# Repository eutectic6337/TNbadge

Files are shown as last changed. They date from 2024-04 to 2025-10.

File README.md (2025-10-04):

# TNbadge

A blinky-light badge in the approximate shape of Tennessee

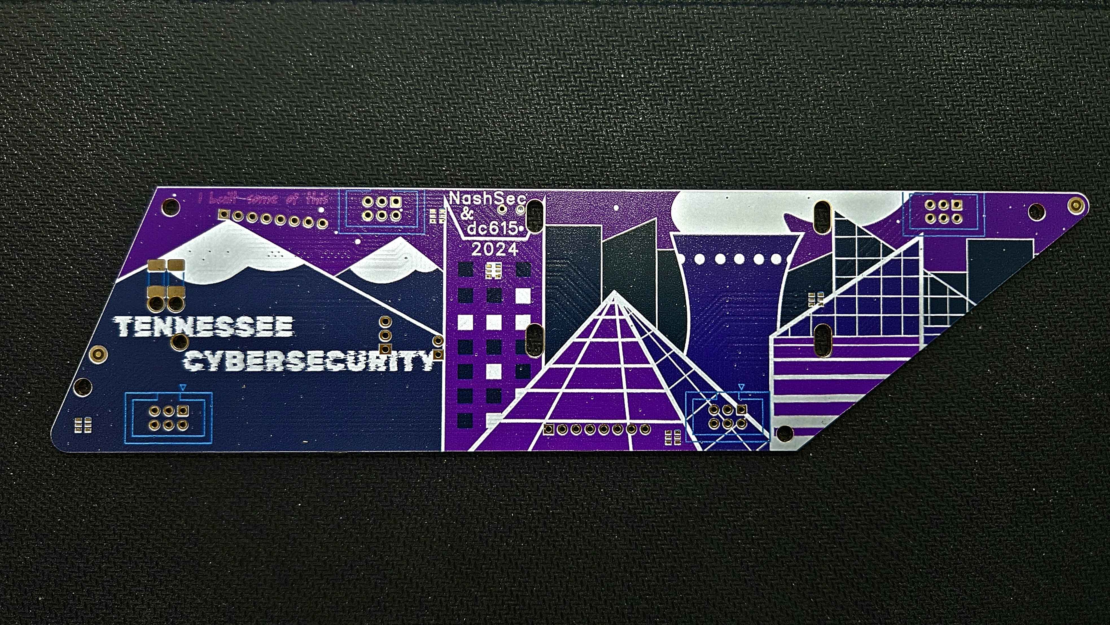
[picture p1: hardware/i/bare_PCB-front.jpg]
PCB front


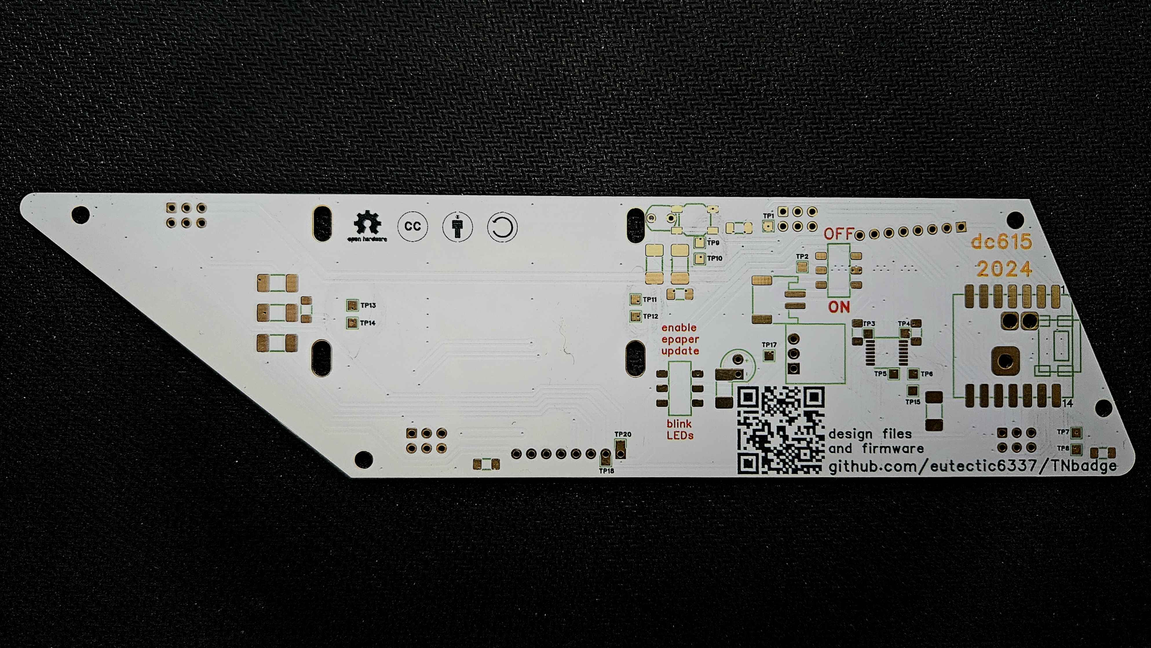
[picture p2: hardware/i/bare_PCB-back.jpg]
PCB back


[Join the Tennessee Cybersecurity Discord](https://discord.gg/tninfosec) and
[participate in discussion about this badge](https://discord.com/channels/781280955667185686/1010244036612862144).

[User's Guide](users-guide.md)

## Features

### human-accessible output
- 5 of [2.0mm square addressable RGB LED (APA102)](https://www.aliexpress.us/item/2251832665711027.html)
at the approximate locations of the top 5 population centres
(west to east: Memphis, Clarksville, Nashville, Chattanooga, Knoxville)  
on-chip SPI (SCLK from pin 9 (D8/GPIO8), MOSI from pin 11 (D10/GPIO10))

- 1 of user-populated [LED](https://www.aliexpress.us/item/3256802159185271.html)-footprint,
[switched](https://www.aliexpress.us/item/2251832541429715.html)
[5V supply](https://www.aliexpress.us/item/3256801453688823.html)
with current-limiting resistor  
from pin 7 (D6/GPIO21)

- 1 of [212x104 pixel 2.13 inch epaper display (grey/black/red)](https://www.aliexpress.us/item/3256806569318405.html)
populated at either of 2 locations
(one almost entirely on-board; one almost entirely off-board and mounted from behind to not obscure Chattanooga's LED)  
on-chip SPI, /CS from pin 4 (D3/GPIO5), DATA/CMD from pin 2 (D1/GPIO3), /RESET from pin 7 (D6/GPIO21), BUSY to pin 1 (D0/GPIO2)

### human-accessible input
- 1 of LDR, darkness-proportional voltage at ADC  
to pin 3 (A3/D3/GPIO5)  
*unfortunately, the chip configuration in Espressif's Arduino chip-support package connects a non-functional ADC to this pin, so this can't work without a deeper dive* :(

- 1 of [pushbutton](https://www.aliexpress.us/item/2251832616067755.html)
digital input to pin 10 (D9/GPIO9)

### electronic
- 1 .. 3 of [SAO V.1.69bis master connector](https://www.aliexpress.us/item/2251832874579437.html)
populated at any of 4 locations not obstructed by epaper  
on-chip I2C (SCL on pin 6 (D5/GPIO7), SDA on pin 5 (D4/GPIO6)), GPIO1 on pin 2 (D1/GPIO3), GPIO2 on pin 1 (D0/GPIO2)

- [USB-C](https://www.aliexpress.us/item/2251832621183502.html)
for power and programming

- [1000mAh LiPo battery](https://www.aliexpress.us/item/3256803012248557.html)

- battery voltage /2 at ADC  
to pin 3 (A2/D2/GPIO4)

- on-chip Bluetooth Low Energy / WiFi

- [power ON/OFF switch](https://www.aliexpress.us/item/2255799844067525.html)

- [epaper display / LED enable switch](https://www.aliexpress.us/item/2255799844067525.html)
(to maximize epaper lifetime by disconnecting power other than when required for update,
and encourage this by having LED power mutually exclusive with epaper power)

## design considerations
- minimal components on front allowing maximum space for silkscreen art

- maximal GND-connected fill on both top and bottom for even background under soldermask (and to reduce electrical noise)

- flat empty space on back for LiPo battery to rest snug against PCB

- maximum flexibility for user customization, both physical and logical

- components chosen (and footprints customized) for hand-solderability where possible

## software
[prototype implementation](https://github.com/eutectic6337/TNbadge/tree/main/software/prototype-1)

ideally, watches for pushbutton held down at boot to signal display update requested;
after display is updated, user flips epaper/LED switch for blinky goodness

possible behaviour-change triggers:
- ambient light level

- dropping battery voltage

- proximity of other badges, which specific badges they are, and *their* interaction history

- external access over BLE/WiFi by not-a-badge

# production timeline
Board design is now locked down.

- First batch of badge kits
(SMD components soldered onto PCB, through-hole assembly to be completed by user)
distributed in April 2024 to software development volunteers

- Artwork has been added to board silkscreen

- epaper displays are now in hand

- remaining PCBs to be delivered mid June

- remaining CPU modules to be ordered mid June

- SMD assembly to start when PCBs arrive

- bagged kits distributed as soon as possible, but no later than
[DEF CON 32](https://defcon.org) in Las Vegas

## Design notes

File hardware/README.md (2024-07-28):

# TNbadge hardware

## Kit

[assembly guide](Kit-assembly.md)

## Printed Circuit Board

- designed in Kicad

- imported into [EasyEDA Pro](https://pro.easyeda.com)

   - manually reattached lanyard/stencil-alignment holes, battery box slots, an zero-size holes to net GND
 with direct connect (i.e. no thermal relief)

   - manually reattached quarter-circle track around pin 2 of epaper display connector, top left,
to net /GPIO1{SLASH}DC

   - manually re-edited APA102 footprint to remove solder mask/stencil openings over (center) duplicate GND/5V pads

   - manually edited all testpoints to show correct designator, on back silkscreen layer

   - manually imported QR code PNG (M1) onto back silkscreen layer (Kicad plays poorly)

   - manually adjusted color of silkscreen artifacts

- multicolour PNG artwork imported to front silkscreen layer

- ordered from [JLC PCB](https://jlcpcb.com)

## component sources

- already in hand (through-hole LDRs)

- [LCSC](https://lcsc.com) (SMD resistors & capacitors)

- [Seeed Studio](https://seeedstudio.com) (CPU module)

- [AliExpress](https://aliexpress.com) (everything else)

# assembly and test

## front surface mount

### assemble

- position PCB back-down on stable heat-resistant surface

- stencil solder paste on front

- [place](i/00-100k-b.jpg) [2x 100k resistor](i/00-100k-a.jpg) (2010)  
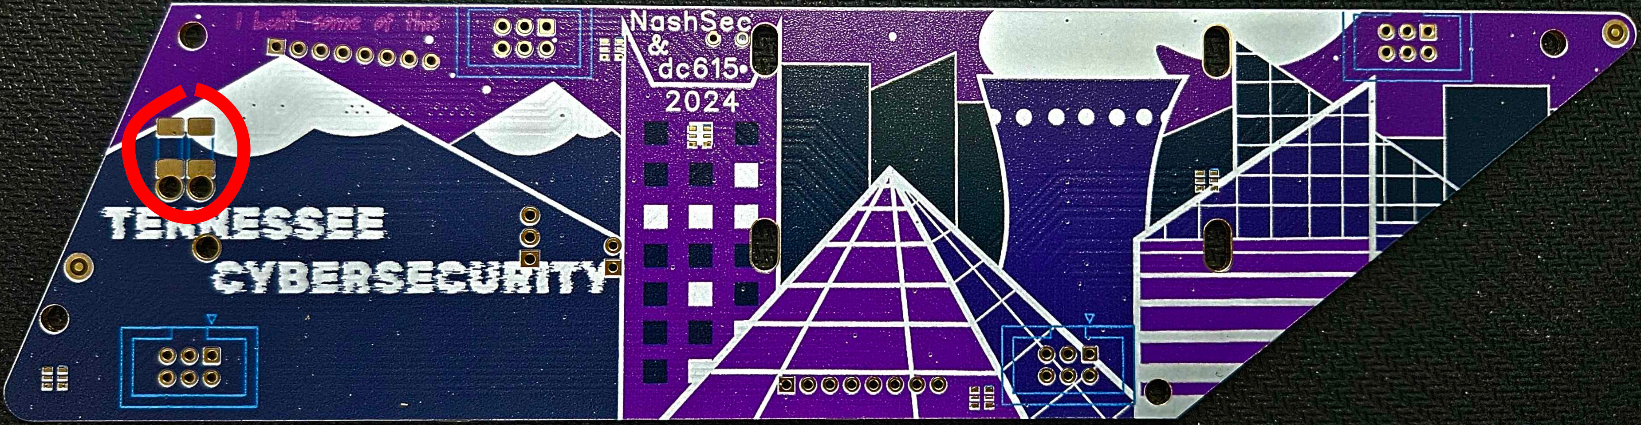
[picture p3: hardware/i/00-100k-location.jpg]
100k location


- [place](i/03-APA102-b.jpg) 5x [APA102 addressable RGB LED](i/03-APA102-a.jpg) (2020)  
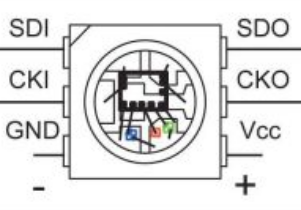
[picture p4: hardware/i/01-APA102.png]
APA102 datasheet

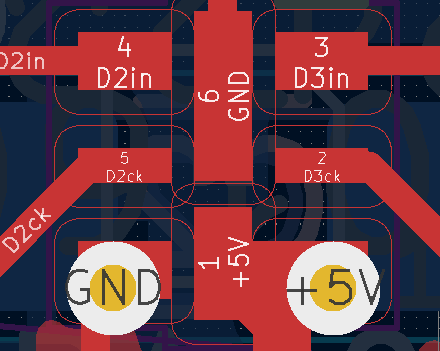
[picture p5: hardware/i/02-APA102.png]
APA102 footprint

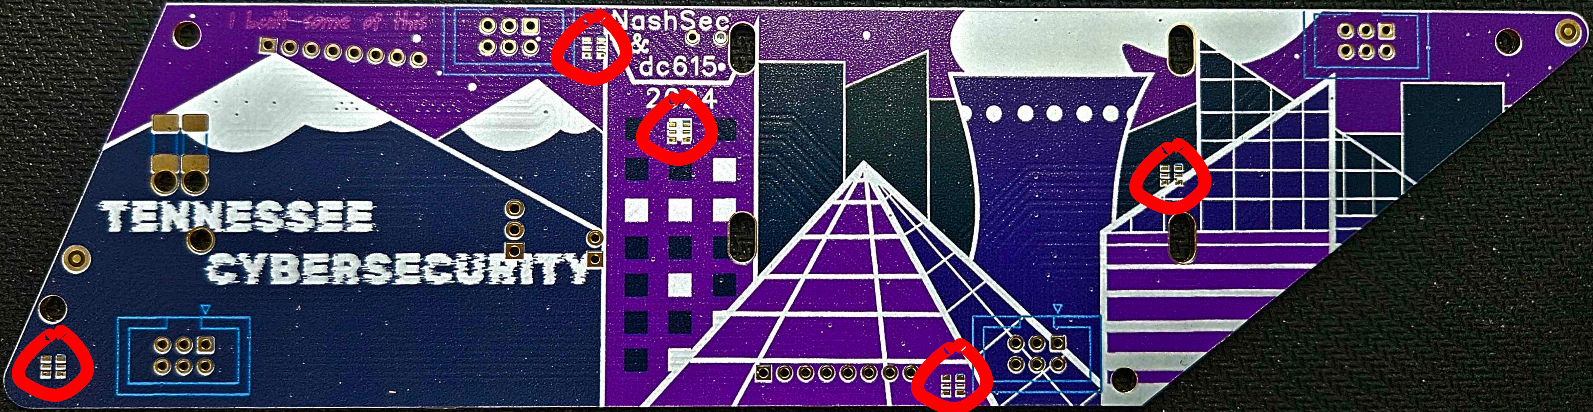
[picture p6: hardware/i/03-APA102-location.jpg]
APA102 location


- (optional) preheat to 100 degC

- apply hot air at 200+ degC to each component until solder flows to create concave surface

### test

- position board front-down on stable non-conductive surface

- starting at lower right corner, test continuity between each pair of pads from the set
{test points, CPU pads}

- continuity is expected between

   - TP1 CPU13 CPU\_GND CPU\_BAT-

   - TP2 CPU\_BAT+

   - TP3 CPU12

   - TP15 CPU8

   - TP18 CPU7

   - TP20 CPU1

- continuity between any pair of test points,
or between any pair of CPU pads,
or between any other test points and CPU pads
indicates a likely solder bridge

- continuity between any of TP5 through TP14 and TP4 or TP1
indicates a bridge between pads of one of the smart LEDs either side of the
involved TP5...TP14

Data point: after soldering only the front components (5x smart LED, 2x resistor) on 5 boards,
I had *1* board with no erroneous beeps in the continuity test.

### rectify

For each identified fault

- desolder identified likely culprit components

- flux and wick up solder from PCB

- re-test to verify fault is gone; if fault remains, dig deeper

- flux pads and reposition component

- reflow remaining solder

- add minimal solder if needed

- re-test to verify fault is gone

Mr Clumsyhands has found a trap for young players:
once you've played some hot air over a SMD LED,
its little transparent top becomes soft enough for your tweezers to wipe it off,
along with the actual silicon bits underneath, if you twitch while applying pressure to the side of the package.

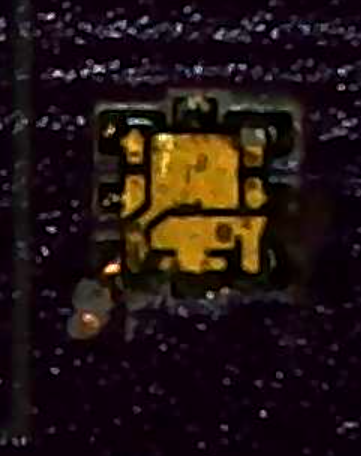
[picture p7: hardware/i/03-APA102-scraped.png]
APA102 scraped


So, don't do that.

## back surface mount

### assembly

- position PCB front-down on stable heat-resistant surface

- stencil solder paste on back

- [place](i/04-TXS0104-b.jpg) [1x level shifter chip](i/04-TXS0104-a.jpg) (TSSOP)
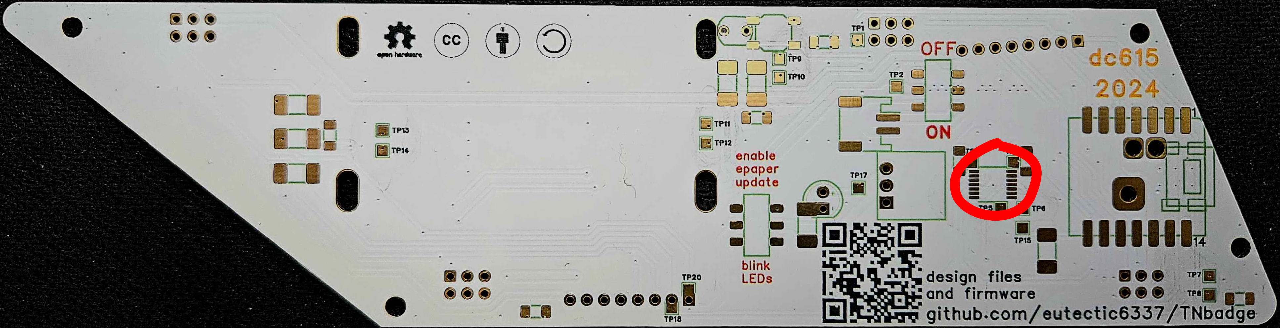
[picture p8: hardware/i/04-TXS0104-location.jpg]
level shifter location


- [place](i/05-pbsw-b.jpg) [1x pushbutton switch](i/05-pbsw-a.jpg)
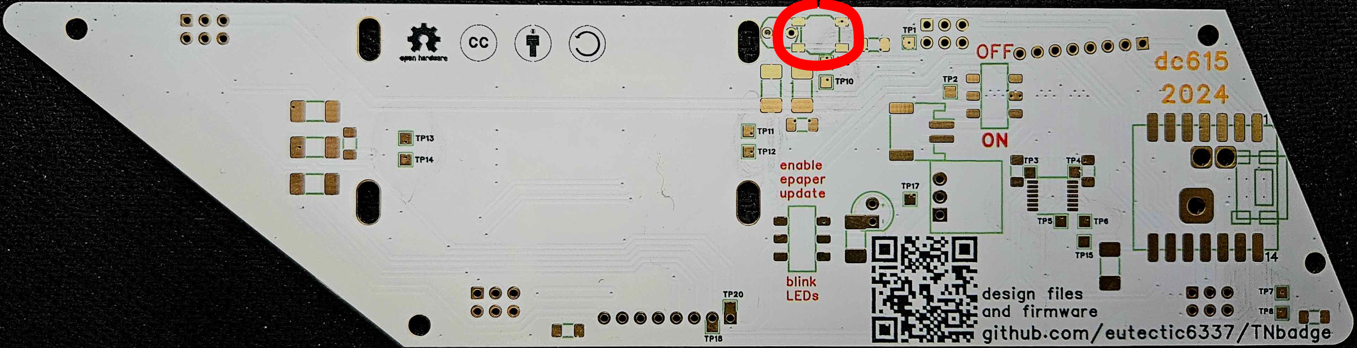
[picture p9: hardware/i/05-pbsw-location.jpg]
pushbutton location


- place 1x 100 ohm resistor (2010)
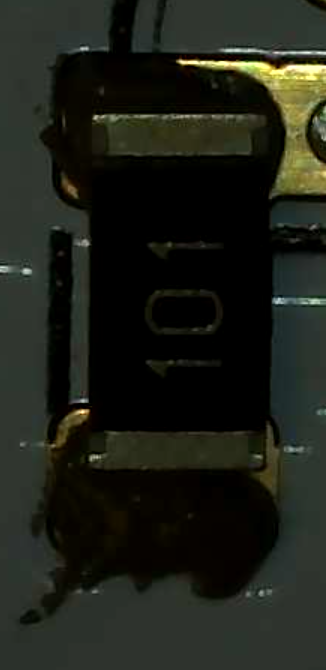
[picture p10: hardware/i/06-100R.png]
100 ohm surface mount resistor


- [place](i/07-10k-b.jpg) 6x [10k resistor](i/07-10k-a.jpg) (2010)
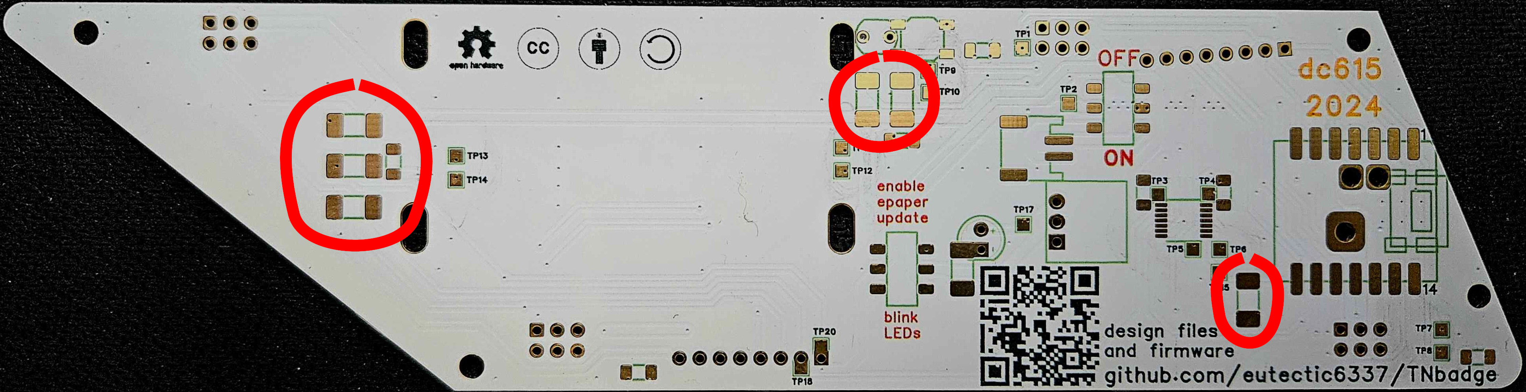
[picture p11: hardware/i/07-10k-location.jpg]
10k location


- [place](i/08-1uF-b.jpg) 7x [1uF capacitor](i/08-1uF-a.jpg) (1206)
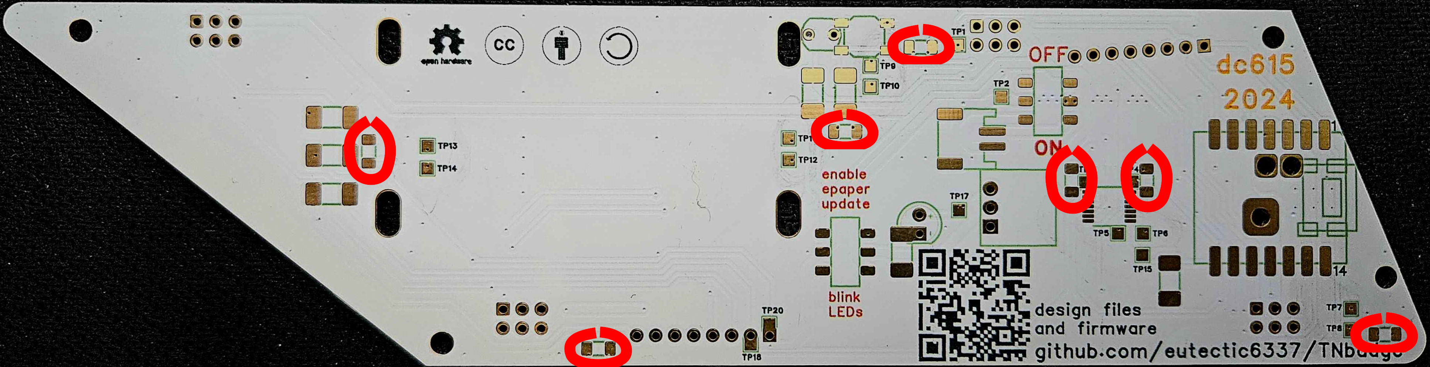
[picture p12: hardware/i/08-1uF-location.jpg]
1uF location


- [place](i/09-pow_sw-b.jpg) 2x [slide switch](i/09-pow_sw-a.jpg)
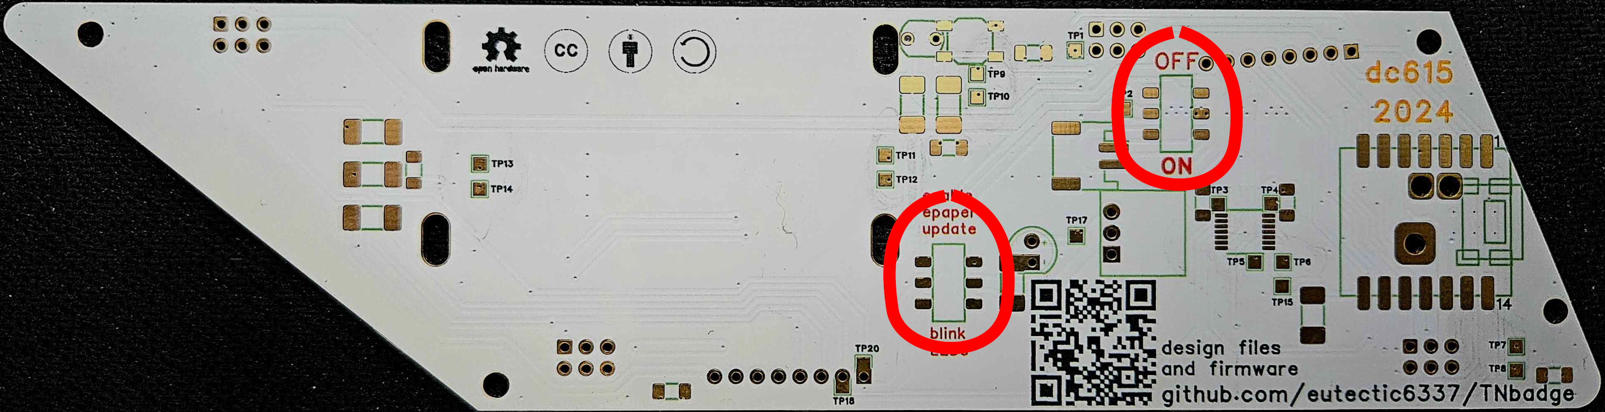
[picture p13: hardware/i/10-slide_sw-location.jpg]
slide switch location


- [place](i/11-batcon-a.jpg) [1x battery connector](i/11-batcon-a.jpg)
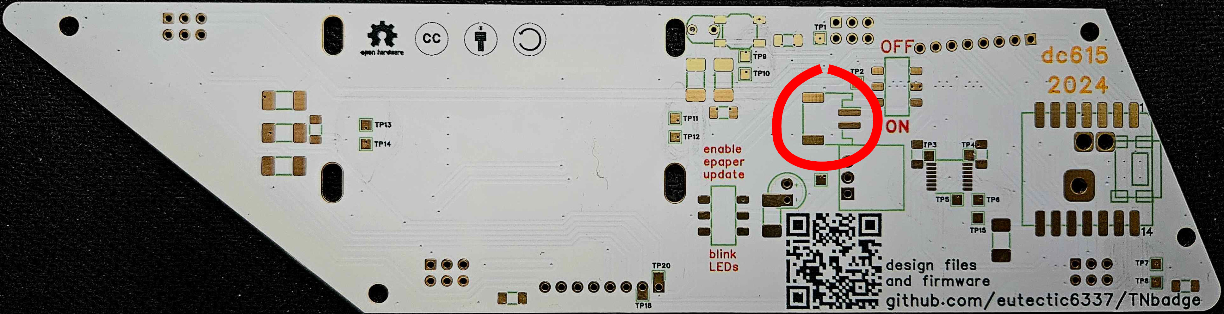
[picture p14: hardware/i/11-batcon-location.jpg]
battery connector location


- (optional) preheat to 100 degC

- apply hot air at 200+ degC to each component until solder flows to create concave surface

### test

- position board front-down on stable non-conductive surface

- starting at lower right corner, test continuity between each pair of pads from the set
{test points, CPU pads}

- continuity is expected between

   - TP1 CPU13 CPU\_GND CPU\_BAT-

   - TP2 CPU\_BAT+

   - TP3 CPU12

   - TP15 CPU8

   - TP18 CPU7

   - TP20 CPU1

- continuity between any pair of test points,
or between any pair of CPU pads,
or between any other test points and CPU pads
indicates a likely solder bridge

### rectify

most likely location for bridge is TSSOP level shifter chip

- flux and wick up excess solder from pins on one side

- drag-solder with small wedge/chisel tip iron to reflow remaining solder

- re-test to verify fault is gone; if fault remains, dig deeper

For each other identified fault

- desolder identified likely culprit components

- flux and wick up solder from PCB

- re-test to verify fault is gone; if fault remains, dig deeper

- flux pads and reposition component

- reflow remaining solder

- add minimal solder if needed

- re-test to verify fault is gone

## CPU module

### assembly

- position PCB front-down on stable heat-resistant surface

- apply small dot of solder paste on each of 14 main CPU pads on PCB

- place ESP32C3 CPU module
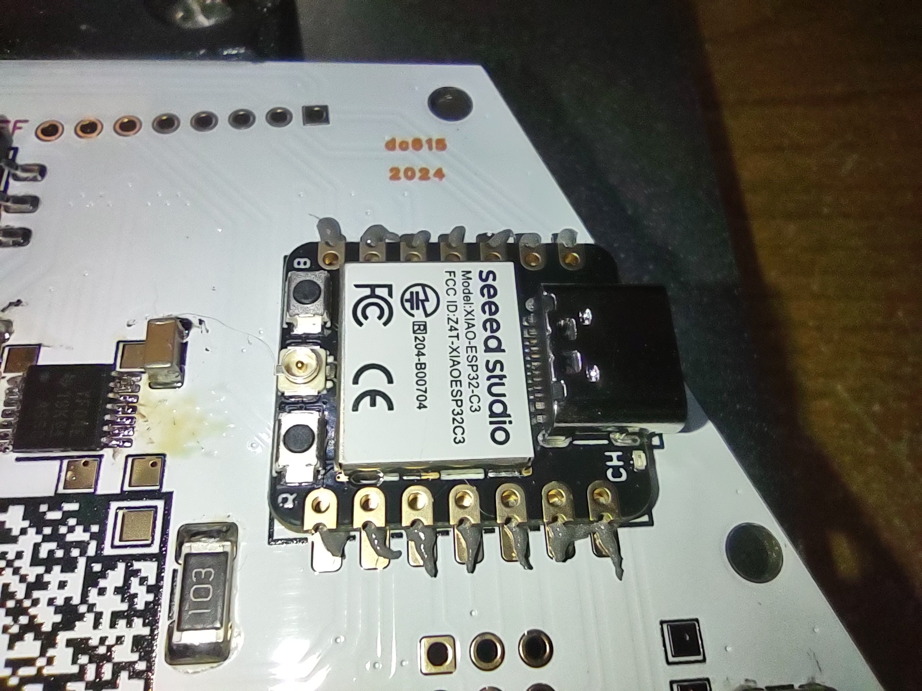
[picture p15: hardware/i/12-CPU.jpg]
CPU module


- apply hot air at 200+ degC to each long edge of CPU carrier board
until solder flows to create concave surface
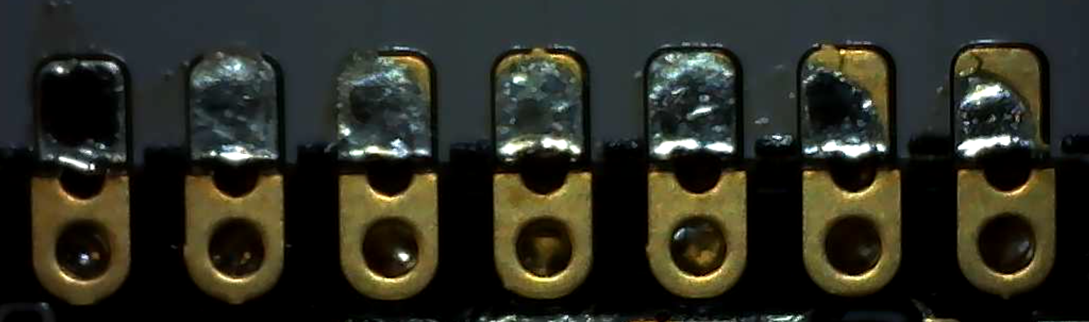
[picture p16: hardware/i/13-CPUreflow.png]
CPU pads after reflow

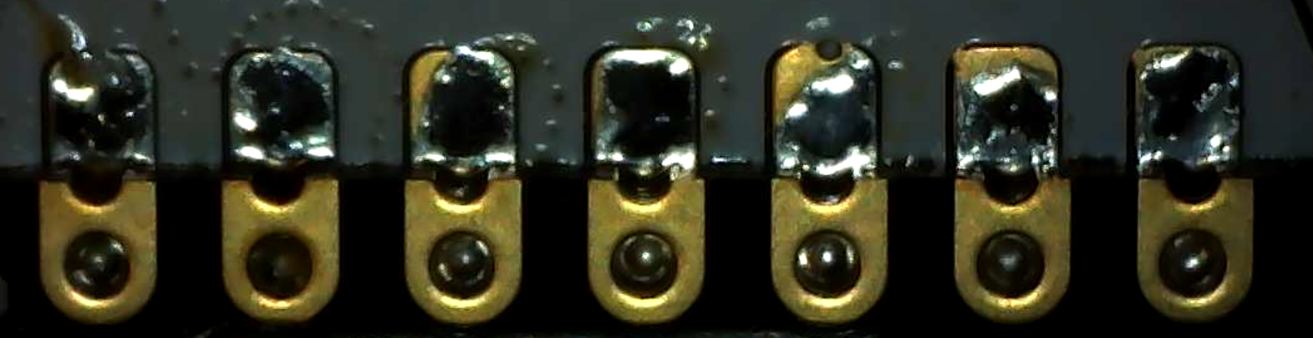
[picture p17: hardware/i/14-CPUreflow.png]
CPU pads after reflow


- position PCB back-down on stable heat-resistant surface

- apply small dot of solder paste in each of 3 through-holes under CPU module
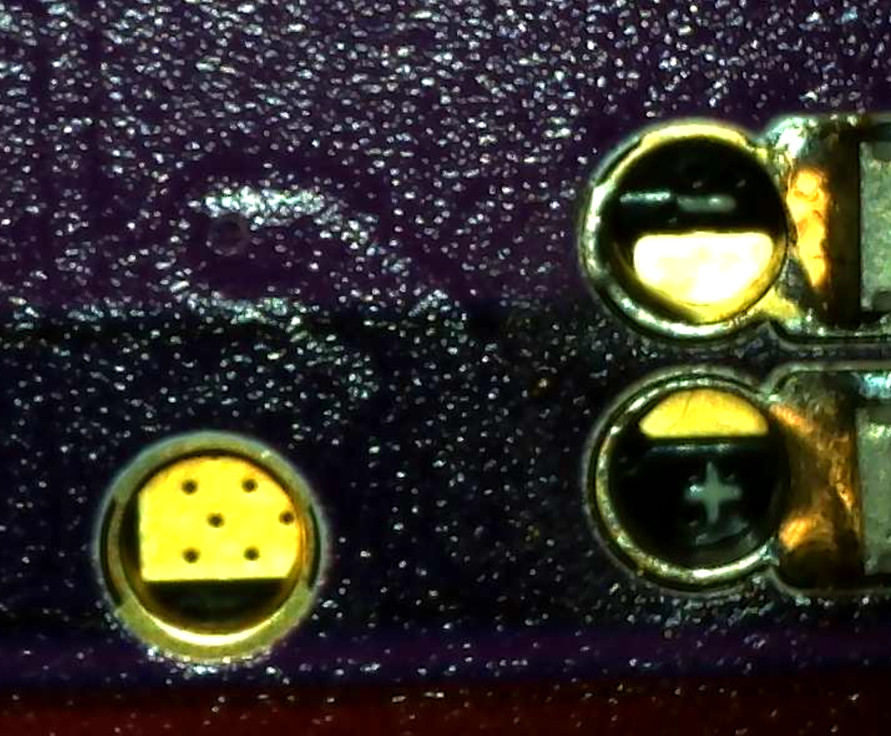
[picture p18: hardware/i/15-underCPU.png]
view through holes to CPU module

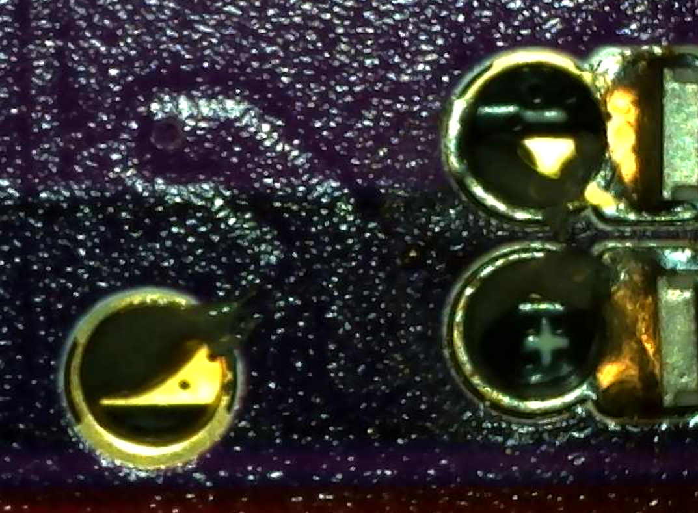
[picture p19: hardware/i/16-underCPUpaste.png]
solder paste in holes


- apply hot air at 200+ degC to holes under CPU carrier board
until solder flows to create concave surface
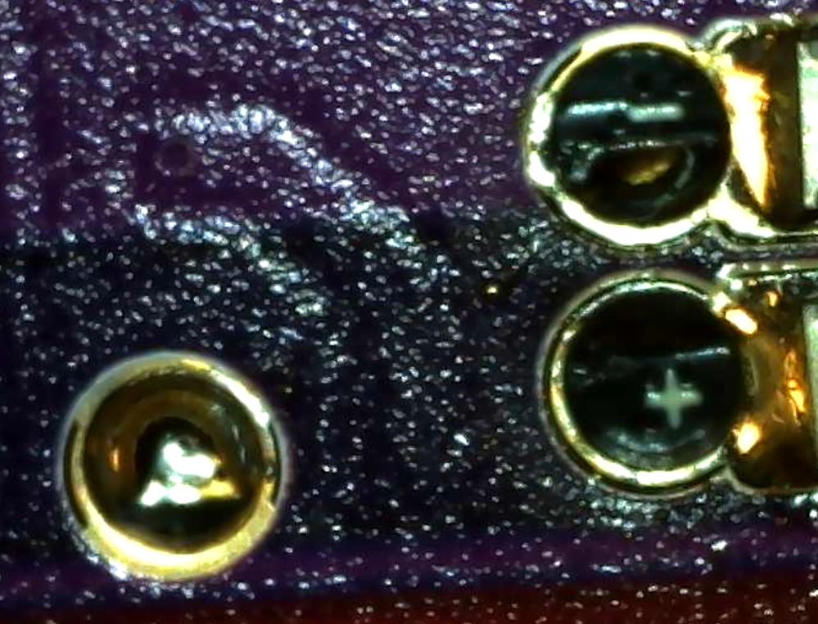
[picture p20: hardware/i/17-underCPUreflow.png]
reflowed solder in holes


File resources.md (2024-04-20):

[public repo](https://github.com/eutectic6337/TNbadge)

# Xiao ESP32C3

[order MCU module](https://www.seeedstudio.com/Seeed-XIAO-ESP32C3-p-5431.html)

[MCU docs](https://wiki.seeedstudio.com/XIAO_ESP32C3_Getting_Started/)

[Arduino support pack](https://raw.githubusercontent.com/espressif/arduino-esp32/gh-pages/package_esp32_index.json)

to Reflash factory firmware

- get [ESP RF Test Tool and Test Guide](https://www.espressif.com/en/support/download/other-tools)

- get [factory firmware](https://files.seeedstudio.com/wiki/XIAO_WiFi/Resources/ESP32-C3_RFTest_108_2b9b157_20211014.bin)

## bootloader

[ESP-IDF](https://docs.espressif.com/projects/esp-idf/en/stable/esp32/api-guides/bootloader.html)

[MCUboot](https://docs.mcuboot.com/)

wouldn't it be nice if we used something like the [Adafruit nRF52 bootloader](https://github.com/adafruit/Adafruit_nRF52_Bootloader)
which supports drag-and-drop of [USB Flashing Format (UF2) files](https://github.com/Microsoft/uf2)

## Zephyr

[hardware support](https://docs.zephyrproject.org/latest/boards/seeed/xiao_esp32c3/doc/index.html)

# addressable RGB LEDs

[FastLED](https://github.com/FastLED/FastLED)

[Adafruit NeoPixel](https://github.com/adafruit/Adafruit_NeoPixel)

[Adafruit NeoMatrix](https://github.com/adafruit/Adafruit_NeoMatrix_ZeroDMA)

[Adafruit GFX](https://github.com/adafruit/Adafruit-GFX-Library)

[Adafruit NeoMatrix](https://github.com/adafruit/Adafruit_NeoMatrix)

# e-paper display

[tutorial at digikey](https://www.digikey.com/en/maker/tutorials/2022/how-to-use-an-e-ink-display-in-your-arduino-project)

[sample code from waveshare](https://www.waveshare.com/w/upload/7/73/1.54inch_e-Paper_Module_code.7z)

[Adafruit EPD](https://github.com/adafruit/Adafruit_EPD)

some product logos



















<svg role="img" viewBox="0 0 24 24" xmlns="http://www.w3.org/2000/svg"><title>Bluetooth</title><path d="M12 0C6.76 0 3.1484 2.4895 3.1484 12S6.76 24 12 24c5.24 0 8.8516-2.4895 8.8516-12S17.24 0 12 0zm-.7773 1.6816l6.2148 6.2149L13.334 12l4.1035 4.1035-6.2148 6.2149V14.125l-3.418 3.42-1.2422-1.2442L10.8515 12l-4.289-4.3008 1.2422-1.2441 3.418 3.4199V1.6816zm1.748 4.2442v3.9687l1.9844-1.9843-1.9844-1.9844zm0 8.1816v3.9668l1.9844-1.9844-1.9844-1.9824Z"/></svg>
#0082FC

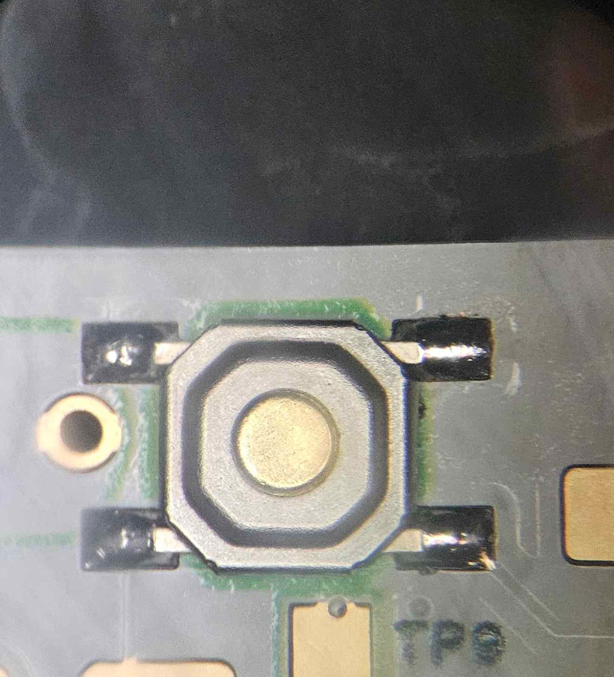
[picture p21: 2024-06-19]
hardware/i/05-pbsw-b.jpg

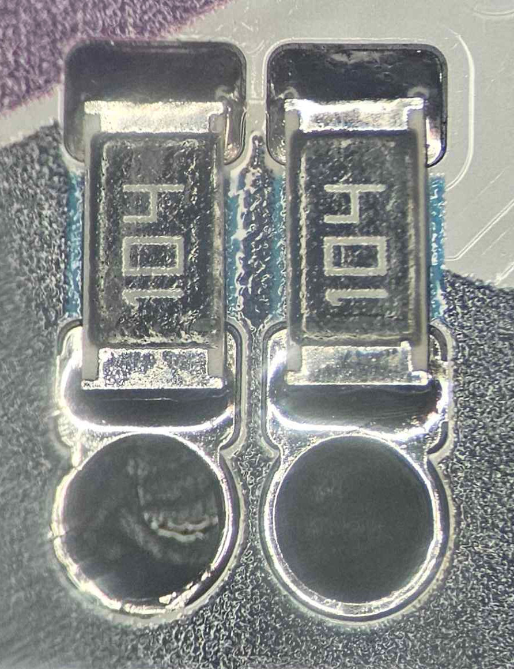
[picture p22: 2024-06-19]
hardware/i/00-100k-b.jpg

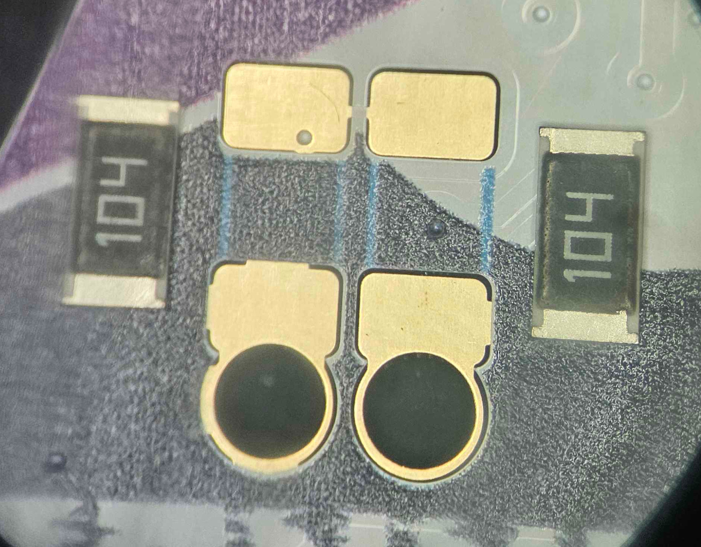
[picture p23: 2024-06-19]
hardware/i/00-100k-a.jpg

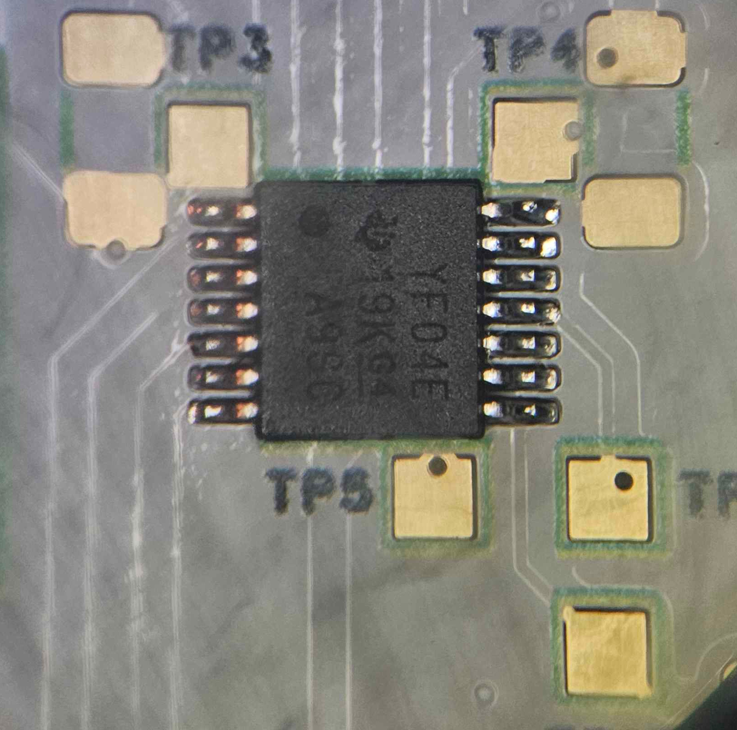
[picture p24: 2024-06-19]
hardware/i/04-TXS0104-b.jpg

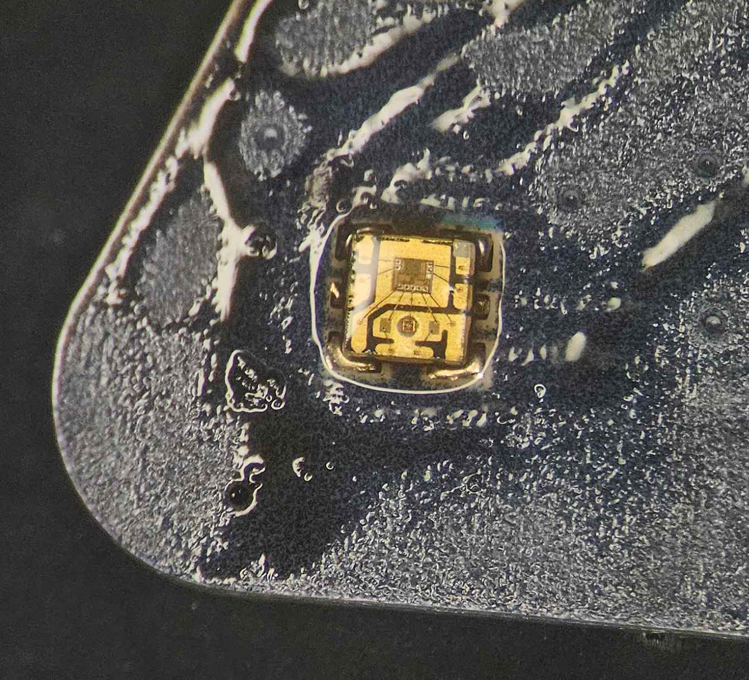
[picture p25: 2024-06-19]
hardware/i/03-APA102-b.jpg

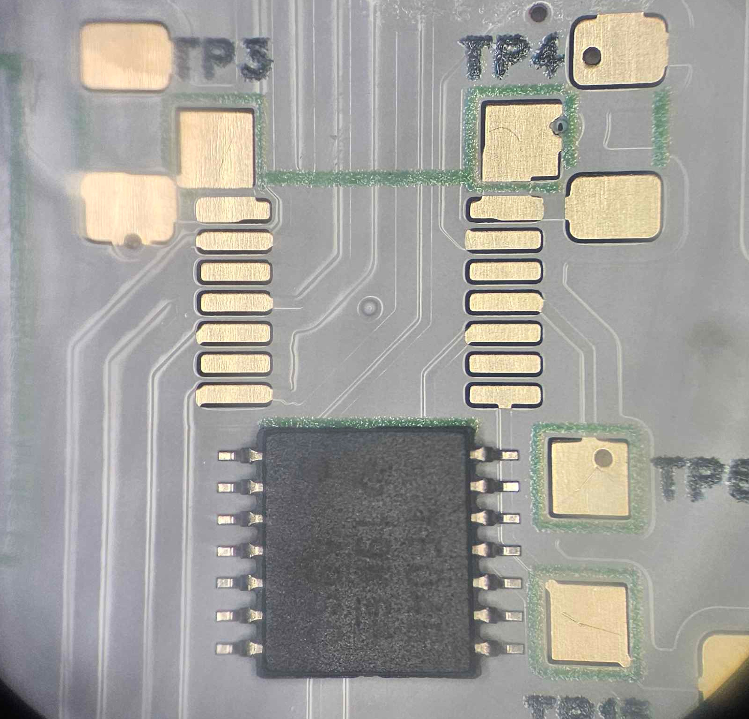
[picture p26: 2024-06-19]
hardware/i/04-TXS0104-a.jpg

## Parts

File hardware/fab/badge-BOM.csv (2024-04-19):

Id | Designator | Footprint | Quantity | Designation | Supplier and ref | Alternates …
1 | D2,D1,D4,D5,D3 | LED-APA102-2020 | 5 | APA102 | aliexpress.com/item/2251832665711027.html
2 | J1,J1,J1,J1 | IDC-Header_2x03_P2.54mm_Vertical | 4 | SAO V.1.69bis host | aliexpress.com/item/2251832874579437.html
3 | U2,U2 | MH-ET_epaper_ 2.13 | 2 | MH-ET_epaper_ 2.13 | aliexpress.com/item/3256803898542103.html,2.13 inch,Red+Black | aliexpress.com/item/2255799844067525.html
4 | R9,R10 | R_2010_5025Metric_Pad1.40x2.65mm_HandSolder | 2 | 100k | lcsc.com/product-detail/C3018350.html,SCR2010J100K
5 | R3,R41,R4,R1,R5,R7 | R_2010_5025Metric_Pad1.40x2.65mm_HandSolder | 6 | 10k | lcsc.com/product-detail/C3018304.html,SCR2010J10K
6 | R11 | R_2010_5025Metric_Pad1.40x2.65mm_HandSolder | 1 | 100 | lcsc.com/product-detail/C5140279.html,SCR2010J100R
7 | C41,C1,C4,C2,C3,C5,C42 | C_1206_3216Metric_Pad1.33x1.80mm_HandSolder | 7 | 1u | lcsc.com/product-detail/C377070.html,TCC1206X7R105M500HT
8 | D6 | LED_D5.0mm | 1 | LED | aliexpress.com/item/3256802159185271.html,pink 3V 300mm
9 | R2 | R_LDR_5.1x4.3mm_P3.4mm_Vertical | 1 | LDR07 | P1241-05 (I had a bagful hanging around for over a decade)
10 | BT1 | JST_PH_S2B-PH-SM4-TB_1x02-1MP_P2.00mm_Horizontal | 1 | Battery | aliexpress.com/item/2255800499298414.html,2pin
11 | SW1 | MSS-22D18G2 hand-solderable | 1 | power | aliexpress.com/item/2255799844067525.html
12 | SW3 | MSS-22D18G2 hand-solderable | 1 | update epaper | aliexpress.com/item/2255799844067525.html
13 | U3 | boost converter module | 1 | 5V boost converter | aliexpress.com/item/3256801453688823.html
14 | SW2 | SW_SPST_SKQG_WithoutStem | 1 | SW_Push | aliexpress.com/item/2251832616067755.html,SKQGABE010
15 | U4 | TSSOP-14_4.4x5mm_P0.65mm | 1 | TXS0104EPWR | aliexpress.com/item/2251832541429715.html,TXS0104EPWR
16 | U1 | Seeed XIAO ESP32-C3 hand-solderable | 1 | Seeed XIAO ESP32-C3 | seeedstudio.com/Seeed-XIAO-ESP32C3-p-5431.html
 |  | 523450 LiPo battery | 1 |  | aliexpress.com/item/3256803012248557.html

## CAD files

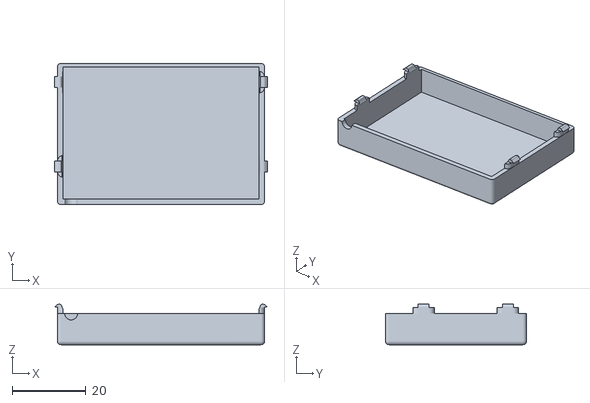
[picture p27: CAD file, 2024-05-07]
hardware/Battery_Box.stl
57.8 x 38.3 x 11.0

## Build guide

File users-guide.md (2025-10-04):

# TNbadge User's Guide

## charge

- connect battery

- silde switch OFF / *ON*

- slide switch *enable epaper update* / blink LEDs

- connect USB-C cable to charge

## wear

- connect battery

- silde switch OFF / *ON*

- slide switch enable epaper update / *blink LEDs*

## modify

- silde switch OFF / *ON*

- slide switch *enable epaper update* / blink LEDs

- connect USB-C cable to computer
`

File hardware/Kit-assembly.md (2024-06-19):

# TNbadge Kit Assembly Guide

You've just been handed a Ziplock bag with a partially-assembled blinky-badge kit inside.
What now?

## What's in the bag?

(almost-) Full kit, from left:

- 30cm flexible LED, nominally pink, that you can use as the single LED

- 1000mAh Li-ion cell, will power this CPU (driving LEDs but without radio) for 24 hours continuous

- baggie containing boost converter, light sensor, and 3x Shitty-Add-On connectors

- USB C to USB C cable, for charging the battery and programming the CPU

- epaper display, and radio antenna with sticky back, in a box

- lanyard to clip onto holes in the top of the badge

missing:

- 3d-printed battery box to clip onto the back of the badge, into the 4 slots (supplied by @Lucien)

*Photo goes here*

## But I don't want a 30cm flexible pink LED

If you'd prefer a "normal" LED rather than the 30cm flexible one, I can toss in one or two red/green/yellow on request.
(I have hundreds and there's no way I'll use them all before I die, even though I plan to live forever.)

## If I were to go full monkey and do YOLO science with my board, will there be replacements available to purchase?

(thanks, @r0nk)

You can always make your own - the Kicad files
(and description of what I had to do to use JLCPCB's Colorful Silkscreen feature),
and also Gerber plots and Bill-Of-Materials including URLs for supplier pages, are all up here.

## OK, what do I need to do?

Get together parts and tools:

### Relevant parts from the packaged kit

(leave the epaper display alone for now ...)

bottom: the PCB, front side down as we'll start with through-hole parts on the back

top right: the little Zip-lock baggie with (from right)
- 3 Shitty Add On connectors
- 1 Light Dependent Resistor
- 1 boost converter module, with 3-pin header

top left: an assortment of Light Emitting Diodes, including the 30cm soft-flexible one that's in the kit as originally packed, and several "normal" ones which I can hand out if you want just a single spot rather than a pink glowy string

*Photo goes here*

### Tools you'll need

- a decent quality, ideally temperature controlled, soldering iron with a fairly fine tip;  
this is my Pinecil which I like very much and is very cheap ($26) if you don't have a suitable iron

*Photo goes here*

- long-nose or needle-nose pliers;  
I bought this pair over 35 years ago in a tool shop in Australia, and I've just recently found some almost identical on Amazon for almost exactly the same number of dollars as I paid

*Photo goes here*

- micro side-cutters or flush nippers;  
I broke the ones I bought with the above pliers, but got this pair from Uncle Jeff

*Photo goes here*

- rosin-flux cored electronics solder, either lead-free or with lead in;  
I don't see much need for lead-free for hobbyist use, as the amount of lead you'd absorb is so low as to be unmeasurable;  
the two rolls here are 1.0mm and 0.5mm diameter, which is about the extremes of useful sizes. If you get lead-inclusive, 63% tin/37% lead is the best alloy for usability. **DO NOT USE anything that mentions "plumbing" or acid.**

*Photo goes here*

- Not shown: a CR2032 coin cell for determining LED polarity.  
I've been playing with these things for more than 40 years now and still don't remember which of the short or long leg, or the flat or round side of the body, is the Anode and which is the Cathode, so I just ask the device.

### Step 1: light sensor

(LDR or light dependent resistor)

Bend its legs at a right angle, about 3mm (1/8") away from its body.

This component doesn't care which way around it is connected to the circuit so which way you choose to bend the legs is irrelevant.

*Photo goes here*

Position the LDR with its sensor face toward the top (longest) side of the badge and insert its legs through the two holes between the pushbutton switch and the nearest battery-box mounting slot.

*Photo goes here*

Push the LDR legs all the way in. Turn the board back-face down and lay it on your work surface - the battery connector will hold it an appropriate distance off the surface for the LDR to rest in the right position ready for soldering. You may want to place a weight on the board to hold it flat - I've used my side-cutters. 

*Photo goes here*

Solder the two legs to the board

- apply hot iron to both leg-of-component and pad-on-board simultaneously,

- apply solder to the heated pad until it melts and flows,

- remove non-melted solder,

- wait a few more seconds for molten solder to go around whole joint and make concave fillets between surfaces,

- remove iron;

- repeat on other leg

Trim the legs close to the board (at about the point where the fillet of solder has dropped to zero thickness)

*Photo goes here*

### Step 2: boost converter module

Put the long end of the 3-pin header into the boost converter module from the low-profile side.

*Photo goes here*

(See *Photo goes here*
 for how this module will sit on the badge)

Flip the board to front-down position again

Solder the 3 pins onto the module, using the same technique you used for the LDR.

*Photo goes here*

(If the pins are not exactly at a right angle to the module board, it's OK.)

Insert the pins into the main badge PCB with the module oriented as indicated by the footprint around the pads;
then flip the badge PCB (holding the module in place) so you can access the end of the pins. 

*Photo goes here*

Solder the pins to the badge.

*Photo goes here*

### Step 3: decision time

Which of the two locations you choose for the epaper display will determine

- which SAO connectors can reasonably be populated, and

- your options for installing the single LED.

*Photo goes here*

In short:

**epaper upper left** =>

- max 2 SAO connectors;

- "normal" LED needs 2 offset bends in its legs to peek out from under the epaper,
or soft flexible LED needs to be inserted from the back;

- and you obscure some of the wonderful art

**epaper lower right** =>

- can install 3 SAO connectors (or even 4, if you're OK with a SAO possibly obscuring the epaper);

- trivial LED install;

- and you see all of @heartsh8ped's artwork

#### epaper to the left

Mounting epaper on the left means two SAO connectors on the right.

*Photo goes here*

#### epaper to the right

Alternatively, the epaper display can be mounted at the lower right of the badge, allowing installation of 3 SAO connectors.

*Photo goes here*

### Step 4: single LED

#### Step 4: single LED on the front

First, verify with a CR2032 coin cell (or, *trust me, bro*) that the long leg of the LED,
which is attached to the small part inside the transparent plastic body, is the positive side or Anode.

*Photo goes here*

Bend the legs so the body of the LED will sit almost at the battery box mounting slot when the legs go through the pads,
Anode toward the top of the badge.

*Photo goes here*

Invert the board ready for soldering (note, longer leg pokes out of hole labeled "+")

*Photo goes here*

Solder and snip, just like the LDR.

#### soft-flexible LED strip on the front

The pin on one end of this has a tiny hole in it - this is the positive end or Anode -
and can also be verified with the old reliable CR2032

*Photo goes here*

insert that pin through the top LED-mounting hole from the front of the badge and again carefully flip the board
(using your needle-nose pliers or tweezers to hold the pin, stopping it from falling out)

*Photo goes here*

insert the other pin and solder

*Photo goes here*

### Step 5: SAO connectors

Note the key sticking out toward the top of the badge, matching the marking on the silkscreen;
get this the wrong way around and best case you SAO won't work, worst case it will release the magic smoke.

*Photo goes here*

Take care when inverting the board to solder these, as they'll just fall straight out if not supported all the way.
Solder 1 pin on each connector first

*Photo goes here*

and then a second (I recommend start with opposite corners) after verifying that all pins poke through the board

*Photo goes here*

Then do the rest of the pins

### Step 6: epaper

#### to the left

The soldering for this is basically a bigger version of what we did on the boost converter module - 8 pins instead of 3.

*Photo goes here*

When mounting the epaper to the top left of the badge,
insert the short side of the 8-pin header into the holes on the epaper board from behind.

*Photo goes here*

Solder one end pin, check that everything is still lined up OK, and solder the other end.

*Photo goes here*

The joints should all be smooth all the way around each pin, and smooth onto the board, preferably concave.
The second image shows that these are marginal - do better than me.

*Photo goes here*

Final step: insert into the badge from the front, and solder behind (end pins first as before).

*Photo goes here*

In the "after" image above, all except the rightmost pin have the shape you're looking for. The rightmost solder joins the PCB at an acute angle and is probably not making good electrical contact, so I re-melted it and applied fresh solder (and more importantly, flux) to the junction of pin and board and left the heat on for a couple seconds longer. It's not great, but it'll do.

*Photo goes here*

#### epaper to the right

In this case, we need to insert the pins into the epaper board from its front

*Photo goes here*

solder them

*Photo goes here*

insert into badge PCB from behind

*Photo goes here*

and solder

*Photo goes here*

These long pins poking out the front are perhaps less needing of a trim than if they poked out the back.
But if you do this assembly and want them trimmed, grab me and my Industrial Cutters.

Oh, and you'll want to peel off the film from the front of the epaper, using the red tab off its top left corner.

### Step 7: battery and battery box

*Photo goes here*

### Step 8: WiFi antenna

Plugging the antenna into the CPU module is ... not fun.

I finally managed it by holding the badge in my left hand thus,
with index finger holding the back of the (teeny) plug in place
over the (tiny) socket as I wriggled it by the cable held in my right hand.
When it looked and felt like it was in the right spot, gentle pressure from left index finger snapped it in place.

*Photo goes here*

### Step 9: trim pins

You'll notice that the pins from the epaper poke through quite a distance here.

If you have a really good (very hard jaws) pair of side-cutters you can use them to cut off these pins.
If you use nice but not-very-hard-jawed cutters, you'll get this
(as I did elsewhere, thus needing to buy my new Hakko cutters).

*Photo goes here*

### Step 10: lanyard

Attach the lanyard to the holes in the top corners of the badge, and it's done.

*Photo goes here*

*Photo goes here*

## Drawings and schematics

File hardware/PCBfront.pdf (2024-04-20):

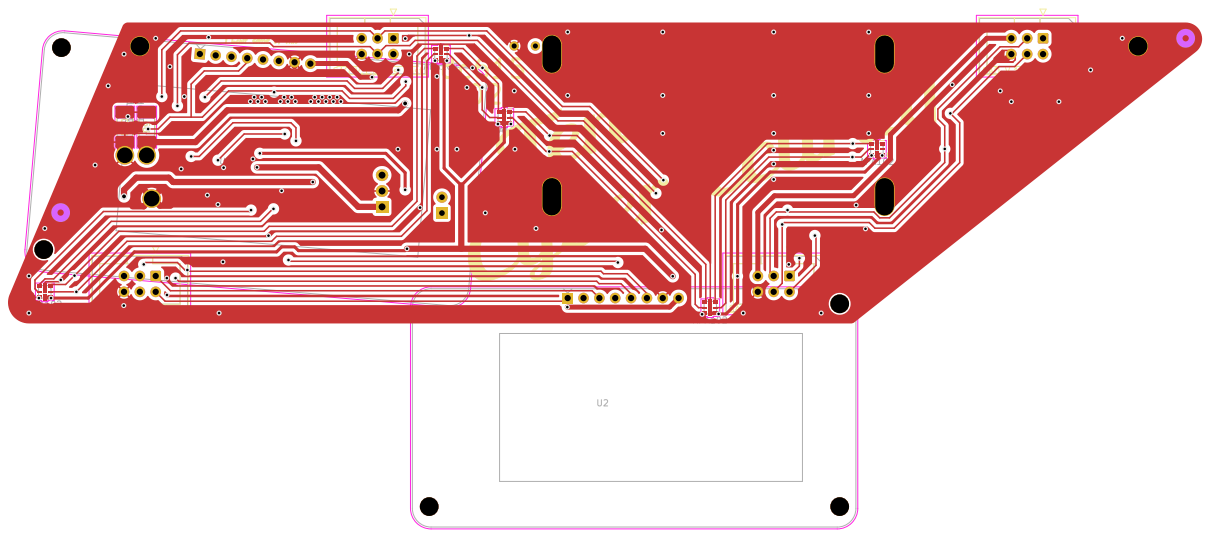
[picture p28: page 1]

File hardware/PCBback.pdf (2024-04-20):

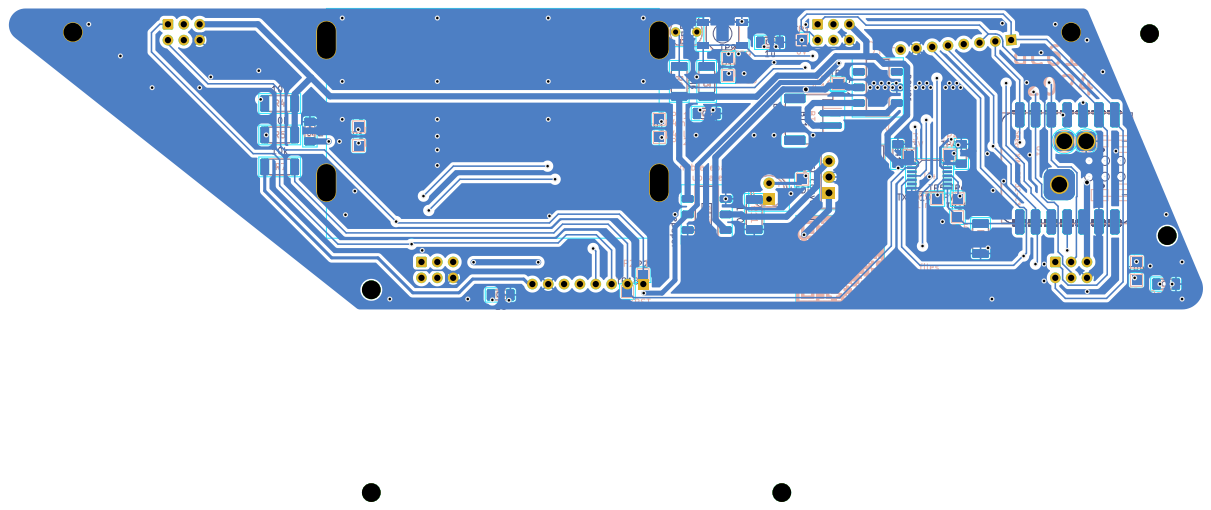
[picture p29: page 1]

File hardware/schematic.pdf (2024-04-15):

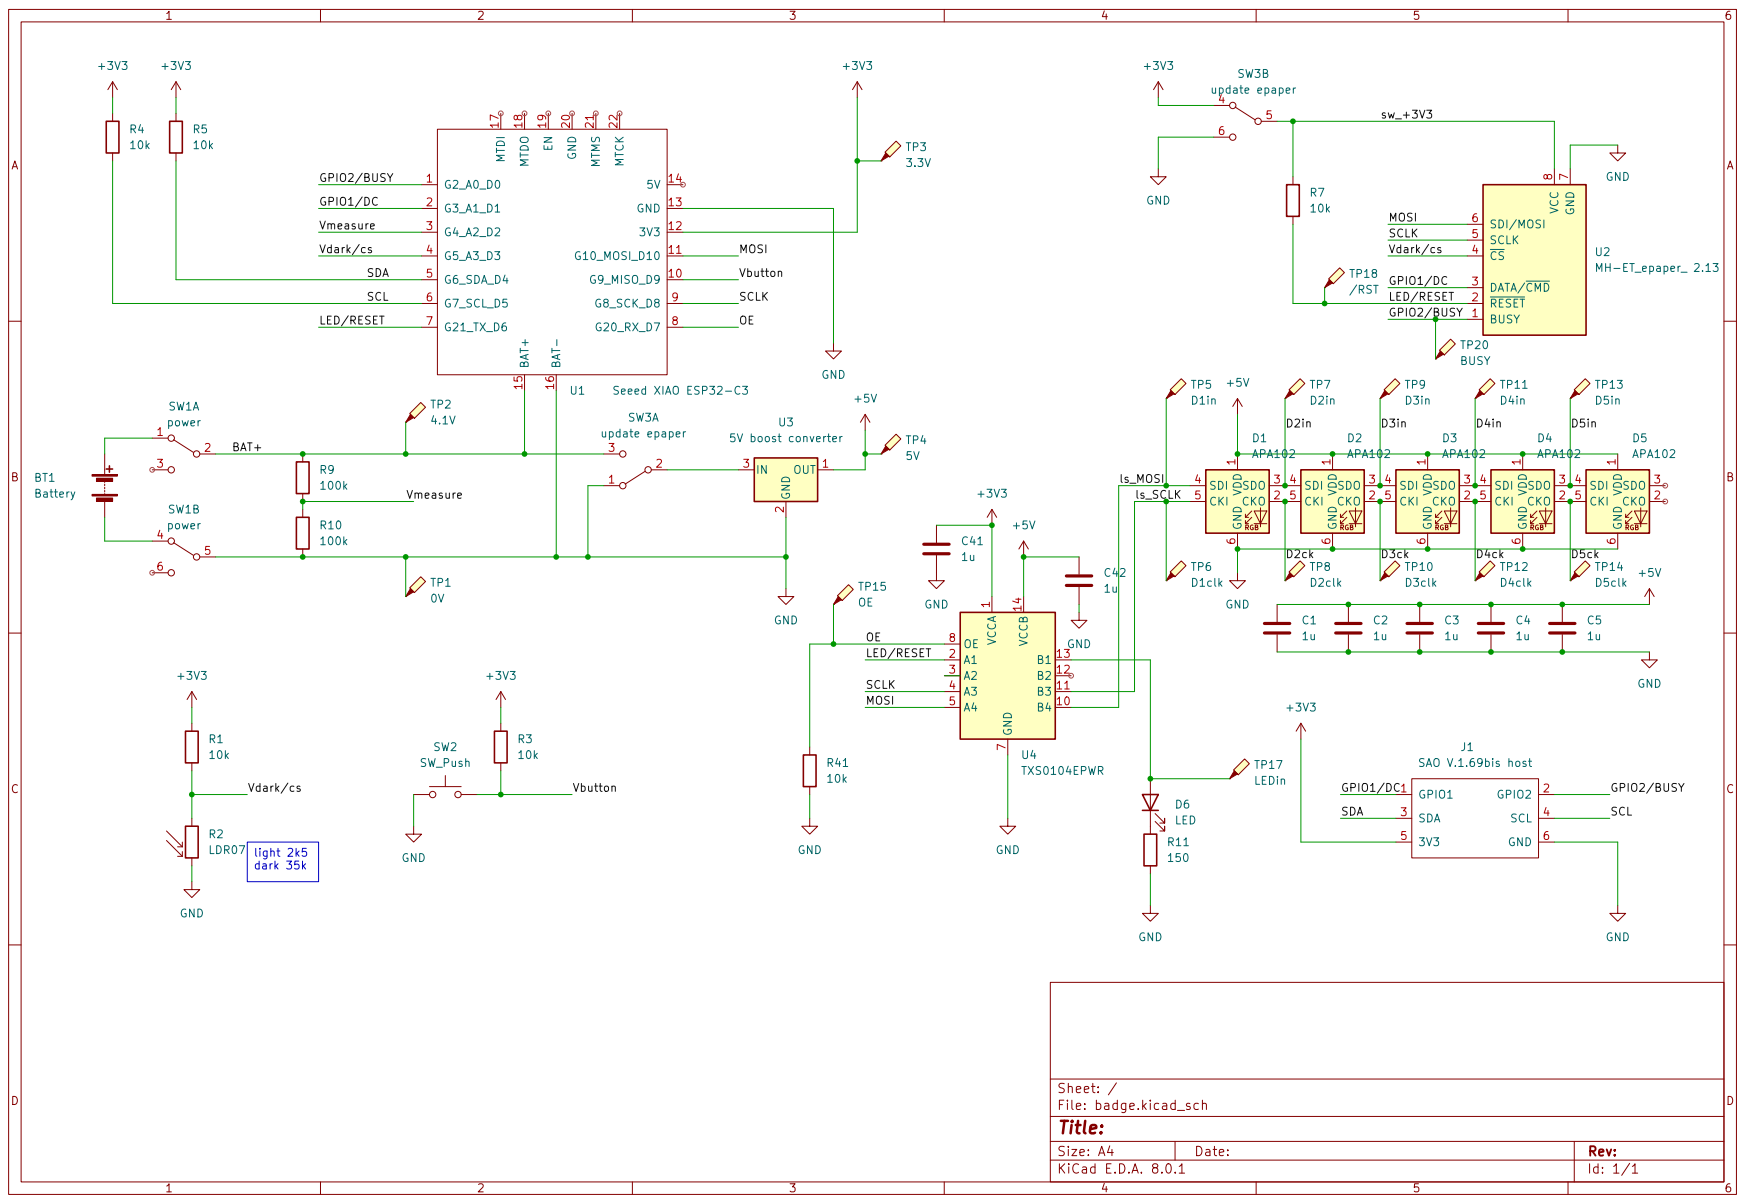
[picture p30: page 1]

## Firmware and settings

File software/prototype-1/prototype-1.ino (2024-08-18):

/*
  Tennessee Cybersecurity / dc615
  2024 blinky-badge
  (https://github.com/eutectic6337/TNbadge)
 */

//
// NOTES FOR BADGE WEARERS
//
// 1. each intended customization location is marked
//    "// ======== CUSTOMIZE HERE ========"
//
// 2. each feature uses a state machine,
//    initialized in setup_FEATURE(),
//    maintained in loop_FEATURE()
//

/* remove leading // to enable; add // to disable feature */
#define ENABLE_EPAPER
#define ENABLE_SMARTLEDS
#define ENABLE_LED
//#define ENABLE_BLUETOOTH
#define ENABLE_WIFI
#define ENABLE_BATTERYMONITOR
//#define ENABLE_LIGHTDARK

/* resources:
  https://learn.adafruit.com/multi-tasking-the-arduino-part-1
 */

// define to disable progress logging to serial port
//#define NDEBUG
#include "badge.h"
#include "badge_pins.h"

// functions on board:
#include "badge_radio.h"
#include "badge_epaper.h"
#include "badge_smartled.h"
#include "badge_led.h"
#include "badge_pushbutton.h"
#include "badge_battery.h"
#include "badge_lightdark.h"
#include "badge_sao.h"

#include "badge_prefs.h"

// IDEA: hold pushbutton down for 5s -> go into deep sleep, wake up on button press
// see deep-sleep sample at https://wiki.seeedstudio.com/XIAO_ESP32C3_Getting_Started/
// DOWNER: only D0..D3 supported for wakeup; could use a SAO GPIOpin, though.

void setup() {
  setup_serial();// so other code can produce diagnostics, or interact
  setup_prefs();
  /* odd-one-out:
     only modify EPD at powerup, and only if explicitly requested
     because EPD has limited lifetime and slow response
     so we generally treat it as a static display */
  setup_epaper_display();

  setup_battery_monitor();
  setup_lightdark_sensor();
  setup_pushbutton();

  setup_single_LED();
  setup_city_smartLEDs();

  setup_SAOs();
  setup_radio();
}

// the loop function runs over and over again forever
void loop() {
  loop_prefs();

  loop_battery_monitor();
  loop_lightdark_sensor();
  loop_pushbutton();

  loop_single_LED();
  loop_city_smartLEDs();

  loop_SAOs();
  loop_radio();
}

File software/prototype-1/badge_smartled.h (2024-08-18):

#ifndef BADGE_SMARTLED_H_
#define BADGE_SMARTLED_H_

#ifdef ENABLE_SMARTLEDS
// ======== blinky outputs - city smartLEDs
//#include <SPI.h>
//FIXME: add ESP32C3 hardware SPI support to FastLED
//#define FASTLED_USE_GLOBAL_BRIGHTNESS 1
#include <FastLED.h>


enum LED_city_index {
  LED_Memphis, LED_Clarkesville, LED_Nashville, LED_Chattanooga, LED_Knoxville,
  NUM_SMART_LEDS
};
CRGB leds[NUM_SMART_LEDS];

/*
each LED has nominal colour and brightness
colour and brightness each follow sequences

sequence is array of transitions, speed-adjusted
transition is (linear) ramp of steps from current to target over time
(for color transition, use separate steps for R,G,B)

probably be best implemented using templates,
but I'm insufficiently comfortable with that C++ feature yet, so I'll use
copy-paste for now
*/

struct brightness_transition {int ms;int target;};
struct color_transition {int ms;CRGB target;};

#define NELEM(a) ((sizeof (a))/((sizeof (a)[0])))
#define CITY_BRIGHT(n,s,v) \
const double brightness_sequence_speed_##n s;\
const struct brightness_transition brightness_tx_##n [] = v;
#define CITY_BRIGHT_INIT(n) {brightness_sequence_speed_##n,brightness_tx_##n,NELEM(brightness_tx_##n)}

#define CITY_COLOR(n,s,v) \
const double color_sequence_speed_##n s;\
const struct color_transition color_tx_##n [] = v;
#define CITY_COLOR_INIT(n) {color_sequence_speed_##n,color_tx_##n,NELEM(color_tx_##n)}

#define SQUARE_(a,b,r,t) {0,(a)},{(r)*(t)/100,(a)},{0,(b)},{(100-(r))*(t)/100,(b)}
#define SQUARE(a,b,t) SQUARE_(a,b,50,t)

#define TRIANGLE_(a,b,r,t) {(r)*(t)/100,(a)},{(100-(r))*(t)/100,(b)}
#define TRIANGLE(a,b,t) TRIANGLE_(a,b,50,t)

#define SAWTOOTH(a,b,t) TRIANGLE_(a,b,100,t)
#define REVERSE_SAWTOOTH(a,b,t) TRIANGLE_(a,b,0,t)

#define RAINBOW(t) \
  {(t)/6,CRGB::Red},\
  {(t)/6,CRGB::Orange},\
  {(t)/6,CRGB::Yellow},\
  {(t)/6,CRGB::Green},\
  {(t)/6,CRGB::Blue},\
  {(t)/6,CRGB::Violet}

#include "00-smartled_patterns.h"

struct brightness_sequence {
  double speed;
  struct brightness_transition* tx;
  int n;
};
struct color_sequence {
  double speed;
  struct color_transition* tx;
  int n;
};

struct brightness_sequence city_brightness[] = {
  CITY_BRIGHT_INIT(Memphis),
  CITY_BRIGHT_INIT(Clarkesville),
  CITY_BRIGHT_INIT(Nashville),
  CITY_BRIGHT_INIT(Chattanooga),
  CITY_BRIGHT_INIT(Knoxville)
};
struct color_sequence city_color[] = {
  CITY_COLOR_INIT(Memphis),
  CITY_COLOR_INIT(Clarkesville),
  CITY_COLOR_INIT(Nashville),
  CITY_COLOR_INIT(Chattanooga),
  CITY_COLOR_INIT(Knoxville)
};

struct color_step {
  Time next;
  int delta;
  Time delta_t;
  Time started;
  struct color_transition* tx;
  struct color_sequence* seq;
};
struct brightness_step {
  Time next;
  int delta;
  Time delta_t;
  Time started;
  struct brightness_transition* tx;
  struct brightness_sequence* seq;
};

struct LED_state {
  CRGB color;
  struct color_step Rstep;
  struct color_step Gstep;
  struct color_step Bstep;

  int brightness;
  struct brightness_step bright_step;
} city[NUM_SMART_LEDS];

void setup_city_smartLEDs() {
  pinMode(smart_LED_data, OUTPUT);
  pinMode(smart_LED_clock, OUTPUT);
//  SPI.begin();
//  SPI.beginTransaction(SPISettings(20000000, MSBFIRST, SPI_MODE0));
  FastLED.addLeds<APA102, smart_LED_data, smart_LED_clock, BGR>(leds, NUM_SMART_LEDS);  // BGR ordering is typical
//	FastLED.setBrightness(100);
//  FastLED.setMaxPowerInMilliWatts(500);
}

int any_LED_changed = 0;
void loop_city(int i) {
  const Time LOG_DELAY_ms = 2000;
  static Time log_delay;
  // ======== CUSTOMIZE HERE ========

  Time now = millis();

  //Brightness
  if (now >= city[i].bright_step.next) {
    any_LED_changed = 1;
    city[i].brightness += city[i].bright_step.delta;
    city[i].bright_step.next += city[i].bright_step.delta_t;
  }
  if (now > city[i].bright_step.started + city[i].bright_step.tx->ms) { 
    struct brightness_sequence* s = city[i].bright_step.seq;
    struct brightness_transition* t = city[i].bright_step.tx + 1;
    if (t >= s->tx + s->n) {// at end of sequence
      t = s->tx;
    }
    city[i].bright_step.started = now;
    int d = t->target - city[i].brightness;
    if (t->ms == 0) {
      city[i].bright_step.delta = 0;
      city[i].bright_step.delta_t = t->ms;
    }
    else {
      int abs_d = abs(d);
      if (abs_d < t->ms) {
        if (d < 0) {
          city[i].bright_step.delta = -1;
        }
        else if (d > 0) {
          city[i].bright_step.delta = 1;
        }
        city[i].bright_step.delta_t = t->ms / abs_d;
      }
      else {
        city[i].bright_step.delta_t = 1;
        city[i].bright_step.delta = d / t->ms;
      }
    }
    if (s->speed) { city[i].bright_step.delta_t *= s->speed; }

    city[i].bright_step.tx = t;
    city[i].bright_step.next = city[i].bright_step.started + city[i].bright_step.delta;
  }

  //Red
  if (now >= city[i].Rstep.next) {
    any_LED_changed = 1;
    city[i].color += CRGB(city[i].Rstep.delta, 0, 0);
    city[i].Rstep.next += city[i].Rstep.delta_t;
  }
  if (now > city[i].Rstep.started + city[i].Rstep.tx->ms) {
    struct color_sequence* s = city[i].Rstep.seq;
    struct color_transition* t = city[i].Rstep.tx + 1;
    if (t >= s->tx + s->n) {// at end of sequence
      t = s->tx;
    }
    city[i].Rstep.started = now;
    int d = t->target.red - city[i].color.red;
    if (t->ms == 0) {
      city[i].Rstep.delta = d;
      city[i].Rstep.delta_t = 0;
    }
    else if (d == 0) {
      city[i].Rstep.delta = 0;
      city[i].Rstep.delta_t = t->ms;
    }
    else {
      int abs_d = abs(d);
      if (abs_d < t->ms) {
        if (d < 0) {
          city[i].Rstep.delta = -1;
        }
        else if (d > 0) {
          city[i].Rstep.delta = 1;
        }
        city[i].Rstep.delta_t = t->ms / abs_d;
      }
      else {
        city[i].Rstep.delta_t = 1;
        city[i].Rstep.delta = d / t->ms;
      }
    }
    if (s->speed) { city[i].Rstep.delta_t *= s->speed; }

    city[i].Rstep.tx = t;
    city[i].Rstep.next = city[i].Rstep.started + city[i].Rstep.delta;
  }
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

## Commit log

2022-11-15 initial upload
    [badge.kicad_sch]
2022-11-16 increased battery-holder attachment-point size
2022-11-17 added simple LED output
    [badge.kicad_sch]
2022-11-18 drive LED with N-MOSFET
    [badge.kicad_sch]
2022-11-18 place GND copper fills on both sides
2022-11-26 disable epaper mod by cutting power (also helps lifetime)
    [badge.kicad_sch]
2022-11-26 refill to generate Gerbers
2022-11-26 move component refs to better indicate; separate some unrelated resistors to avoid confusion
2022-11-28 tweak some tracks to improve GND fill; add dc615 ident
2022-11-29 create simpler front/top silkscreen on User.1
2022-12-01 use updated epaper footprint
    [badge.kicad_sch]
2022-12-06 improve switch function, label switches
    [badge.kicad_sch]
2022-12-06 restore missing pin-marker on silkscreen
2022-12-06 snapshot fab-ready Gerber plots and drill files
    [badge-B_Cu.gbl, badge-B_Mask.gbs, badge-B_Paste.gbp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]
2022-12-07 fixed fighting pull-up/down on CS/OE but kept paste stencil
    [badge-B_Cu.gbl, badge-B_Mask.gbs, badge-B_Paste.gbp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]
2022-12-07 finalize resistor values, regenerate Gerbers
    [badge-B_Cu.gbl, badge-B_Mask.gbs, badge-B_Paste.gbp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]
2022-12-08 add Bill of Materials
    [badge-BOM.csv]
2023-01-16 update CPU, epaper, smartLED footprints
2023-01-16 regen fab outputs
    [badge-B_Cu.gbl, badge-B_Mask.gbs, badge-B_Paste.gbp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]
2023-01-22 fix another whoops - RESET pull-up; add decoupling caps to SmartLEDs
    [badge.kicad_sch]
2023-01-22 cut 3 alternate epaper locations; add SAO; grow battery-box mounting holes
2023-01-22 update fab files
    [badge-B_Cu.gbl, badge-B_Mask.gbs, badge-B_Paste.gbp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]
2023-01-25 update BoM
    [badge-BOM.csv]
2023-01-30 added front silkscreen text
2023-01-30 updated fab files, ordered prototypes
    [badge-B_Cu.gbl, badge-B_Mask.gbs, badge-B_Paste.gbp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]
2023-01-31 clean up some tracks and silkscreen
2023-01-31 update fab files;
    [badge-B_Cu.gbl, badge-B_Mask.gbs, badge-B_Paste.gbp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]
2023-03-18 reverse polarity of battery connector
    [badge.kicad_sch]
2023-03-18 adjust epaper mounting holes to match hardware
2023-03-18 stitch together grounds in a few more places
2023-03-18 move bottom-right epaper 1mm lower
2023-03-18 clean up silkscreen text, DRC
2023-03-18 update fabrication files, and JLCPCB-ready .zip
    [badge-B_Cu.gbl, badge-B_Mask.gbs, badge-B_Paste.gbp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]
2023-04-23 avoid shorting battery-charge output
    [badge.kicad_sch]
2023-04-23 realign some tracks, add more vias stitching GND fills
    [badge.kicad_sch]
2023-05-29 add test points
    [badge.kicad_sch]
2023-06-04 resize vias on power path for more copper
2023-06-04 updated fab files
    [badge-B_Cu.gbl, badge-B_Mask.gbs, badge-B_Paste.gbp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]
2023-06-13 bump up decoupling caps to non-trivial value; change font to Lobster Two
    [badge.kicad_sch]
2023-06-14 updated decoupling cap value; tweaked testpoint locations & silkscreen
    [badge.csv, badge.kicad_sch]
2023-06-25 regenerate fab files
    [badge-B_Cu.gbl, badge-B_Mask.gbs, badge-B_Paste.gbp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]
2023-06-25 update bypass cap spec
    [badge-BOM.csv]
2023-07-07 rearrange repo
    [badge-BOM.csv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]
2023-07-07 shouldn't even be here
    [badge.csv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]
2023-11-17 fix smart LED APA102-2020, and some minor re-routings
    [badge.kicad_sch]
2024-01-16 track/pad cleanup, make all mounting holes PTH to GND
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2024-03-10 rename RESET/LED net to LED/RESET, for consistency with other multi-use pins
    [badge.kicad_sch]
2024-03-10 rename MISO/Vbutton1 net to Vbutton1, for consistency with other single-use pins
    [badge.kicad_sch]
2024-03-10 Arduino sketches to verify basic individual functionality of modules
2024-03-18 tweak some track and via locations, remove epaper mounting holes
2024-03-19 put GND between I2C tracks, improve DRC result
    [badge.kicad_sch]
2024-03-19 put GND between SPI tracks
    [badge.kicad_sch]
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2024-03-19 swap Vdark, Vmeasure CPU pins
    [badge.kicad_sch]
2024-03-19 regenerated fab files
    [badge-B_Cu.gbl, badge-B_Mask.gbs, badge-B_Paste.gbp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]
2024-04-03 relocate cap & res out from battery footprint
2024-04-03 add diode to ensure boost converter Vin < Vo
    [badge.kicad_sch]
2024-04-03 change to higher-rated diode
    [badge.kicad_sch]
2024-04-04 remove voltage-drop diode before boost converter
    [badge.kicad_sch]
2024-04-04 cut MOSFET to drive LED with level-shifter; hard-wire /CS and OE
    [badge.kicad_sch]
2024-04-05 level-shifter datasheet dire warnings re OE wrt power-good means OE is back
    [badge.kicad_sch]
2024-04-05 remove now-unneeded battery-box mounting holes along bottom edge
2024-04-05 improved DRC results and some track routing
    [badge.kicad_sch]
2024-04-06 restore CS control; swap TH-LED to back
    [badge.kicad_sch]
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2024-04-07 further tweaks to have EasyEDA more closely match KiCad
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2024-04-07 move EPD /cs from OE to Vdark
    [badge.kicad_sch]
2024-04-13 beginnings of software: debounce button, smooth analog reads
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2024-04-14 track down which pin (or, castellated pad on module) corresponds to which "pin number" within Arduino
2024-04-14 eliminate compile errors, figure out pin mapping
    [prototype-1.ino]
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2024-04-19 officially change LED current-limiter to 100R
    [badge.kicad_sch]
2024-04-19 updated BOM
    [badge-BOM.csv]
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2024-04-19 updated ancilliary files
    [badge-job.gbrjob]
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2024-04-19 add some blinky-light code, fix some compile eerrors
    [prototype-1.ino]
2024-04-20 relocate QR code + some testpoint labels, increase dc615 text size
    [badge-B_Cu.gbl, badge-B_Mask.gbs, badge-B_Paste.gbp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]
2024-04-20 the rest of the updated fab files
    [badge-Edge_Cuts.gm1, badge-F_Cu.gtl, badge-F_Mask.gts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]
2024-04-20 put soldermask over the two duplicate pads on smart LEDs
    [badge-B_Cu.gbl, badge-B_Mask.gbs, badge-B_Paste.gbp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]
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2024-04-22 avoid reinventing the wheel by reading the Fine manual
2024-04-22 remove wrong-size epd; add descriptive comment
    [prototype-1.ino]
2024-04-22 add a little for smart LEDs; clean out a bogus pasted section
2024-04-22 add some Bluetooth code, grow too big
    [prototype-1.ino]
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2024-04-24 select the right board to get the right definitions
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2024-04-29 fix log-delay code; add crypto ref
    [prototype-1.ino]
2024-05-07 add Lucien's 3D modelled battery box
    [Battery_Box.stl]
2024-05-16 move pin declarations (and definitions) before any possible use of them
2024-05-19 change DO_LOG to (inverted) NDEBUG for consistency with standard
    [prototype-1.ino]
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2024-05-25 found the last missing curly and excess colon, and it compiles
    [00-smartled_patterns.h, badge_smartled.h]
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2024-05-25 disable lightdark sensor, document error message
    [prototype-1.ino]
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2024-06-19 correct TP typo; update assembly images
2024-07-16 toolchain update deprecated pin A3 rather than fix it
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

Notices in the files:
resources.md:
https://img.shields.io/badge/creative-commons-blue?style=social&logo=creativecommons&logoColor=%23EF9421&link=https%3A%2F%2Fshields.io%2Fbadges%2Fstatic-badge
